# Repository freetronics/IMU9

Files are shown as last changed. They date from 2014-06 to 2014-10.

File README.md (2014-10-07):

IMU9
====
http://www.freetronics.com/products/9-dof-imu-accelerometer-gyroscope-magnetometer

Design files for the Freetronics IMU9 - a 9-DOF IMU with I2C interface.

Combining an accelerometer, a magnetometer, and a gyroscope all in one tiny package with an Arduino-friendly I2C interface.

Perfect for building an autopilot for a quadcopter, or tracking the position of a robot, or logging data in a rocket. Combine three axis data from each of the sensors for a total of 9 degrees-of-freedom (DOF) of tracking.

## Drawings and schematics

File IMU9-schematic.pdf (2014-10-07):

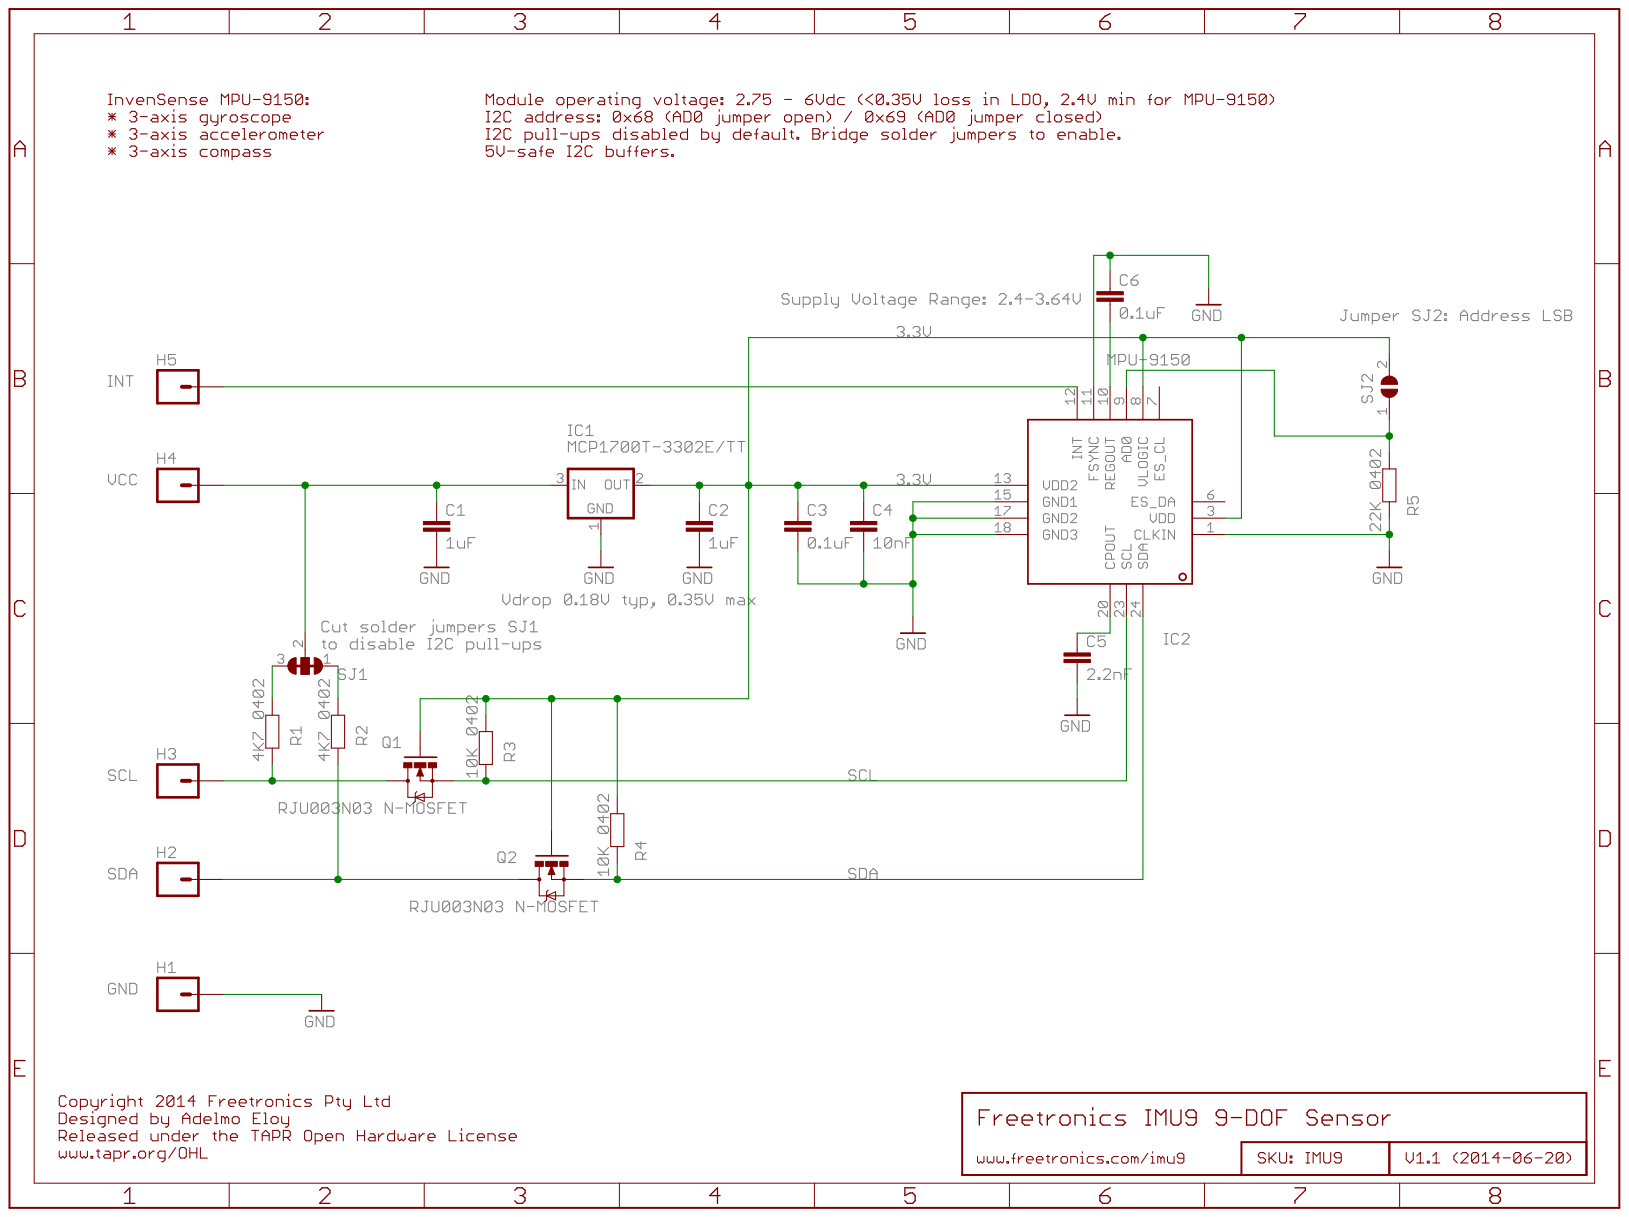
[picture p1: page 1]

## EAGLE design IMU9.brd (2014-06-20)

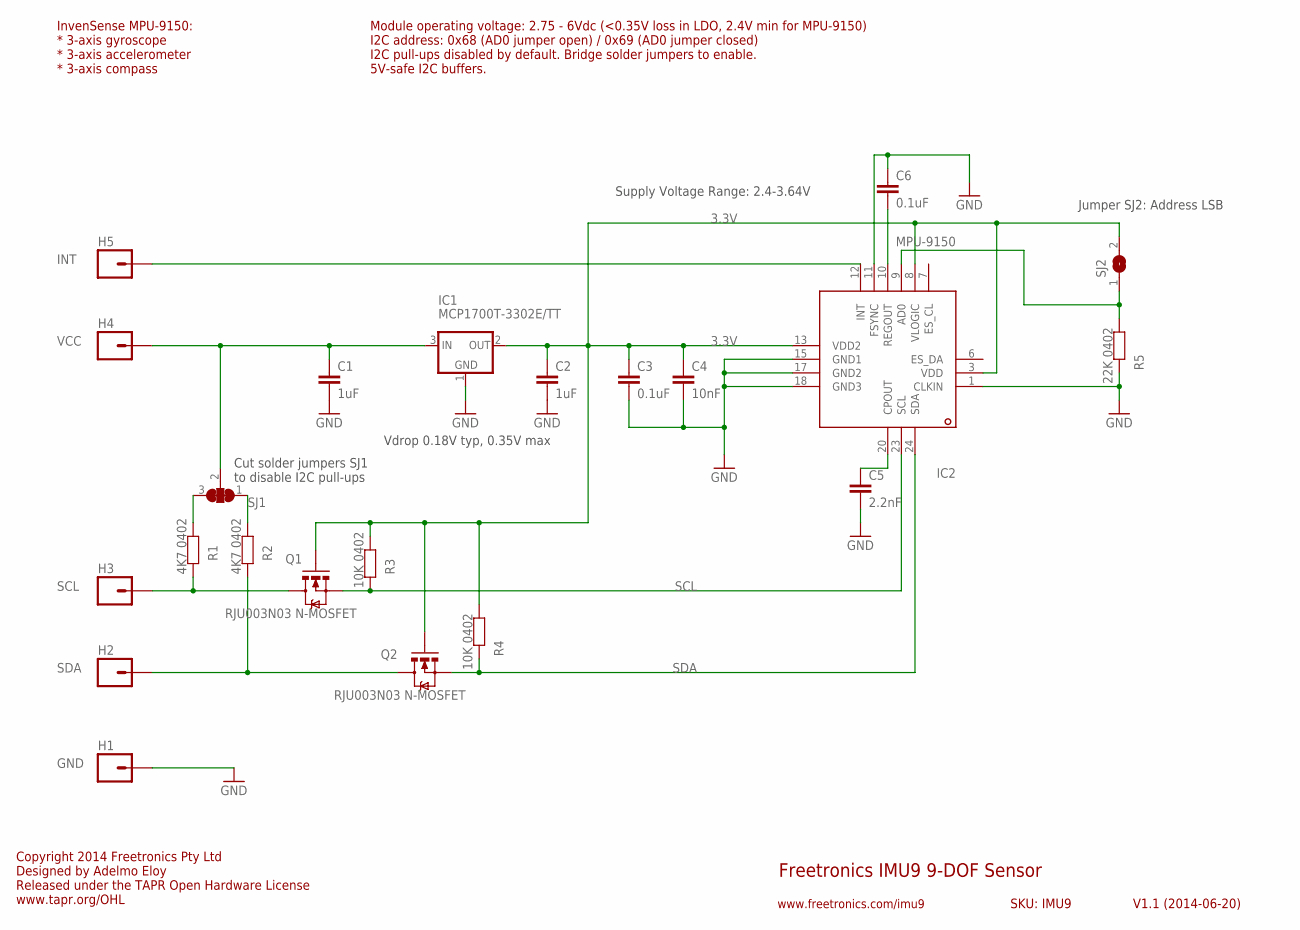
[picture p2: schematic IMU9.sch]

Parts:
C1, C2: 1uF; 0603
C3, C6: 0.1uF; 0603
C4: 10nF; 0603
C5: 2.2nF; 0603
H1: GND; 1X01
H2: SDA; 1X01
H3: SCL; 1X01
H4: VCC; 1X01
H5: INT; 1X01
IC1: MCP1700T-3302E/TT; SOT23-3
IC2: MPU-9150; QFN-24MPU
Q1, Q2: RJU003N03 N-MOSFET; SOT32-3
R1, R2: 4K7 0402; 0402
R3, R4: 10K 0402; 0402
R5: 22K 0402; 0402
SJ1: SJ2W; SJ_2
SJ2: SJ

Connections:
3.3V: C2.1, C3.1, C4.1, IC1.2 (OUT), IC2.3 (VDD), IC2.8 (VLOGIC), IC2.13 (VDD2), Q1.1 (G), Q2.1 (G), R3.2, R4.2, SJ2.2
GND: C1.2, C2.2, C3.2, C4.2, C5.2, C6.1, H1.1, IC1.1 (GND), IC2.1 (CLKIN), IC2.11 (FSYNC), IC2.15 (GND1), IC2.17 (GND2), IC2.18 (GND3), R5.1
unnamed: IC2.23 (SCL), Q1.2 (S), R3.1
unnamed: C5.1, IC2.20 (CPOUT)
unnamed: C1.1, H4.1, IC1.3 (IN), SJ1.2
unnamed: IC2.24 (SDA), Q2.2 (S), R4.1
unnamed: R1.2, SJ1.3
unnamed: R2.2, SJ1.1
unnamed: C6.2, IC2.10 (REGOUT)
unnamed: IC2.9 (AD0), R5.2, SJ2.1
unnamed: H5.1, IC2.12 (INT)
SCL: H3.1, Q1.3 (D), R1.1
SDA: H2.1, Q2.3 (D), R2.1

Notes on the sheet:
Freetronics IMU9 9-DOF Sensor
V1.1 (2014-06-20)
www.freetronics.com/imu9
SKU: IMU9
Supply Voltage Range: 2.4-3.64V
Cut solder jumpers SJ1 to disable I2C pull-ups
Vdrop 0.18V typ, 0.35V max
Jumper SJ2: Address LSB
Copyright 2014 Freetronics Pty Ltd Designed by Adelmo Eloy Released under the TAPR Open Hardware License www.tapr.org/OHL
InvenSense MPU-9150: * 3-axis gyroscope * 3-axis accelerometer * 3-axis compass
Module operating voltage: 2.75 - 6Vdc (<0.35V loss in LDO, 2.4V min for MPU-9150) I2C address: 0x68 (AD0 jumper open) / 0x69 (AD0 jumper closed) I2C pull-ups disabled by default. Bridge solder jumpers to enable. 5V-safe I2C buffers.

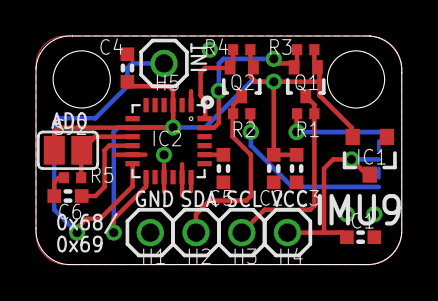
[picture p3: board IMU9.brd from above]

Board: 2 copper layers, 20.3 x 12.7 mm, 22 parts (1 on the bottom side), 13 nets.

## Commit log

2013-12-21 Initial project.
    [IMU9.brd, IMU9.sch]
2014-01-21 Added Adelmo Eloy as designer Added notes to schematic about max parameters Improved silkscreen Improved designator positions Improved part designators and values
    [IMU9.brd, IMU9.sch]
2014-06-20 Bridged across I2C pull-up cut track jumpers Shortened URL
    [IMU9.brd, IMU9.sch]
2014-10-07 Add schematic PDF

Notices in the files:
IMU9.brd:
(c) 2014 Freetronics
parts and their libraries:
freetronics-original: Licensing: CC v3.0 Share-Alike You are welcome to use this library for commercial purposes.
